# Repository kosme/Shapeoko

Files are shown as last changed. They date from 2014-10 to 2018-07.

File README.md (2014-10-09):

#Folder Structure#

##Upgrades##
Contains the folders of each of the upgrades

###xAxisPlate###
Upgrade for obtaining another 40mm of effective cutting length on the X axis by replacing the motor mount and the Z axis face plate.

##README.md##
This document in markdown format.

<br />This work is licensed under a <a rel="license" href="http://creativecommons.org/licenses/by-nc-sa/4.0/">Creative Commons Attribution-NonCommercial-ShareAlike 4.0 International License</a>.

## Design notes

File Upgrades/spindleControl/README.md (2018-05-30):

This shield implements several hacks for my Shapeoko CNC.

1. It disconnects the A-axis stepper motor signals. Now the source for that stepper are the Y-axis control signals. This enables to use a 2 motor Y-axis configuration.
2. It connects pin 11 of the Arduino to an optocoupler to control the spindle speed and activity.
3. It exposes pin 9, 10, and 12 so that they can be easily used to connect limit switches.
4. It exposes all the analog pins for custom implementations.
5. It provides a 5V and Gnd power rails to facilitate powering external accesories.

**Atention**

1. The pinout it uses is based on the original Arduino Stepper Shield. This pinout was later changed so this may not work with your shield.
2. It relies on a hack that connects the PWM signal for the spindle also to pin 12 on the Stepper Shield. This is not an elegant solution but does the trick since that pin is not connected to anything on the Stepper Shield.

All the files can be opened on Kicad 4+.

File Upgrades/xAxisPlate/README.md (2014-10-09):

Attention:

On the file Part1.dxf, the red lines should be verified. There are TWO screw sizes for the delrin Z-axis nut (5mm or 6mm) so the red figures should be adjusted to match the screw size on your machine.

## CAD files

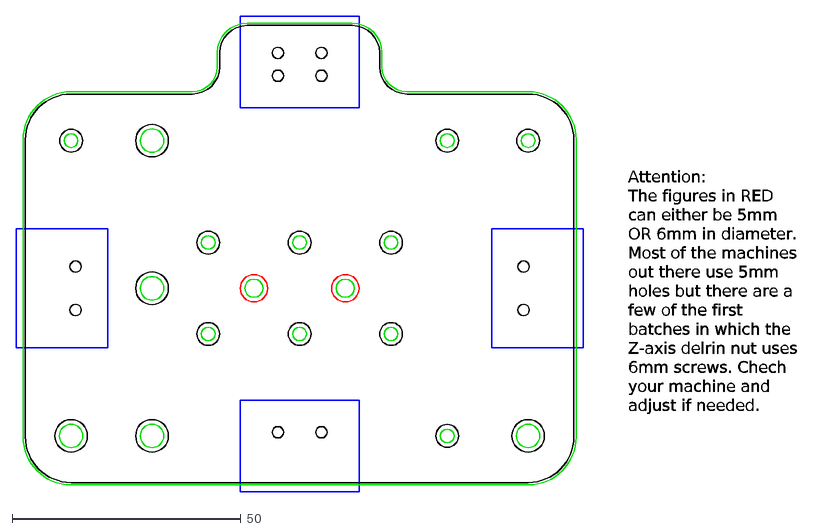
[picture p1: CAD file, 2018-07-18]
Upgrades/xAxisPlate/Part1.dxf
Attention: The figures in RED can either be 5mm OR 6mm in diameter. Most of the machines out there use 5mm holes but there are a few of the first batches in whi

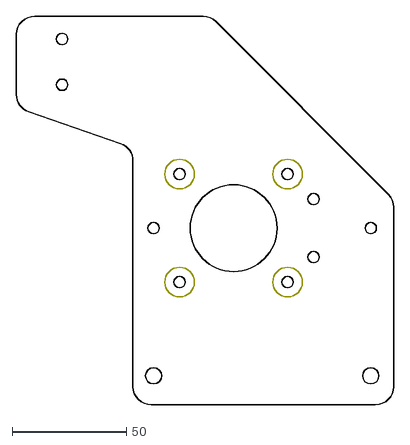
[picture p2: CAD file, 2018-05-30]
Upgrades/yAxisPlate/SM-S01rev3.dxf
165.0 x 170.0

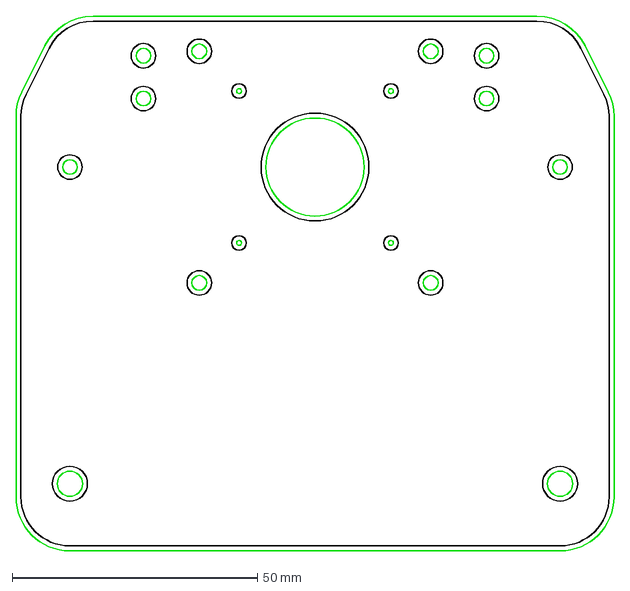
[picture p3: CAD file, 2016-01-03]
Upgrades/xAxisPlate/Part2.dxf
122.0 x 109.1 mm

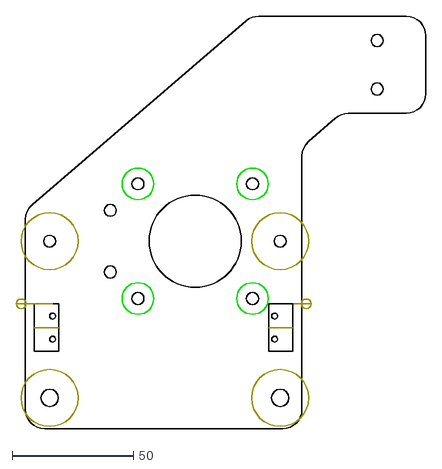
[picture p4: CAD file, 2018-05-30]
Upgrades/yAxisPlate/SM-S01rev2b.dxf
168.8 x 170.0

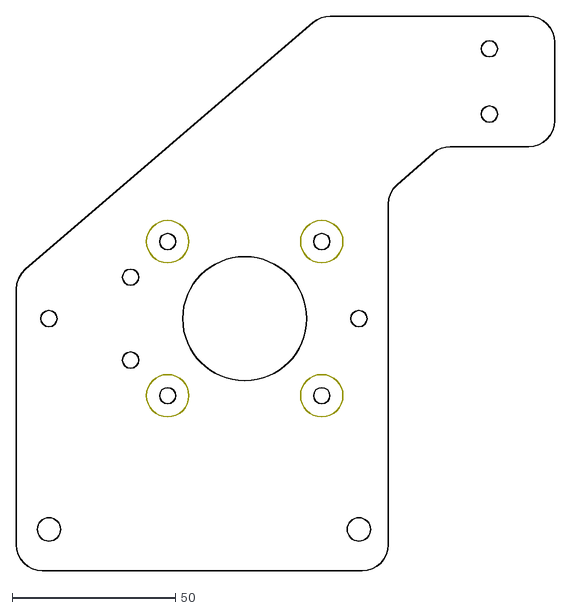
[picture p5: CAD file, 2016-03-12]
Upgrades/yAxisPlate/SM-S01rev2.dxf
165.0 x 170.0

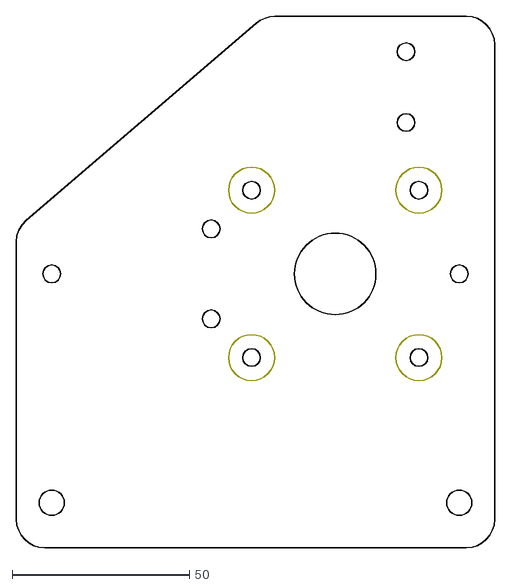
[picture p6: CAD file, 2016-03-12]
Upgrades/yAxisPlate/SM-S01rev1a.dxf
135.0 x 150.0

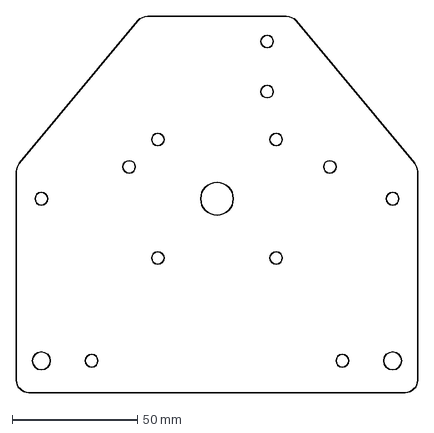
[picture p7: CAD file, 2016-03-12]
Upgrades/yAxisPlate/SM-S01_original.dxf
160.0 x 150.0 mm

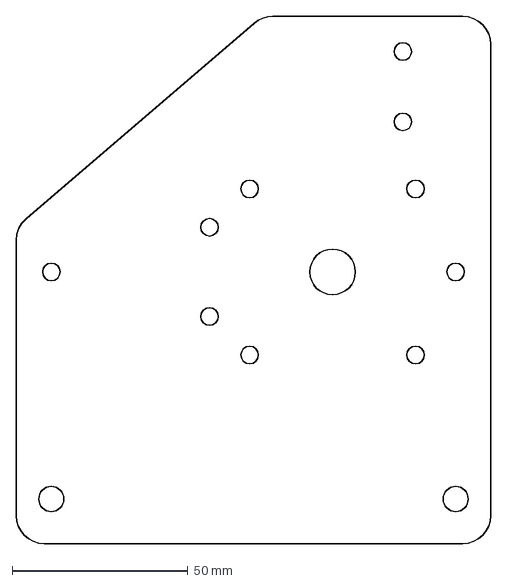
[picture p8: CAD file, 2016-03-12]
Upgrades/yAxisPlate/SM-S01.dxf
135.0 x 150.0 mm

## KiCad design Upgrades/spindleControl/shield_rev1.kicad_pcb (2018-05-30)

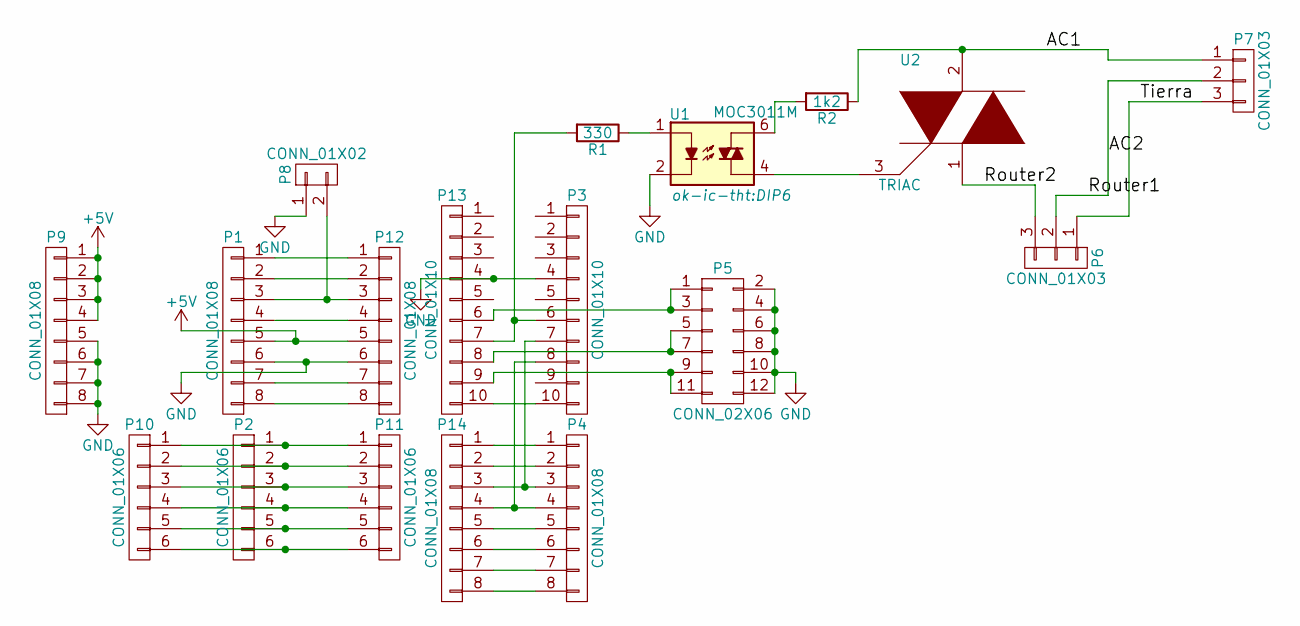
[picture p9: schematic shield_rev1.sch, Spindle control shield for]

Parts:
P1, P4, P9: CONN_01X08; Socket_Strip_Straight_1x08
P2, P10: CONN_01X06; Socket_Strip_Straight_1x06
P3: CONN_01X10; Socket_Strip_Straight_1x10
P5: CONN_02X06; Socket_Strip_Straight_2x06
P6, P7: CONN_01X03; AK300-3
P8: CONN_01X02; AK300-2
P11: CONN_01X06; Pin_Header_Straight_1x06
P12, P14: CONN_01X08; Pin_Header_Straight_1x08
P13: CONN_01X10; Pin_Header_Straight_1x10
R1: 330; Resistor_Horizontal_RM10mm
R2: 1k2; Resistor_Horizontal_RM10mm
U1: MOC3011M; DIP6
U2: TRIAC; TO-220_Neutral123_Horizontal_Reverse_LargePads

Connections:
+5V: P1.5, P9.1, P9.2, P9.3, P9.4, P12.5
/AC1: P7.1, R2.1, U2.2
/AC2: P6.2, P7.2
/Router2: P6.3, U2.1
/Tierra: P6.1, P7.3
GND: P1.6, P3.4, P5.2, P5.4, P5.6, P5.8, P5.10, P5.12, P8.1, P9.5, P9.6, P9.7, P9.8, P12.6, P13.4, U1.2
unnamed: P1.1, P12.1
unnamed: P1.2, P12.2
unnamed: P1.3, P8.2, P12.3
unnamed: P1.4, P12.4
unnamed: P1.7, P12.7
unnamed: P1.8, P12.8
unnamed: P2.1, P10.1, P11.1
unnamed: P2.2, P10.2, P11.2
unnamed: P2.3, P10.3, P11.3
unnamed: P2.4, P10.4, P11.4
unnamed: P2.5, P10.5, P11.5
unnamed: P2.6, P10.6, P11.6
unnamed: P5.1, P5.3, P13.6
unnamed: P3.6, P13.7, R1.2
unnamed: P5.5, P5.7, P13.8
unnamed: P5.9, P5.11, P13.9
unnamed: P3.10, P13.10
unnamed: P4.1, P14.1
unnamed: P4.2, P14.2
unnamed: P3.7, P4.3, P14.3
unnamed: P3.8, P4.4, P14.4
unnamed: P4.5, P14.5
unnamed: P4.6, P14.6
unnamed: P4.7, P14.7
unnamed: P4.8, P14.8
unnamed: R1.1, U1.1
unnamed: R2.2, U1.6
unnamed: U1.4, U2.3

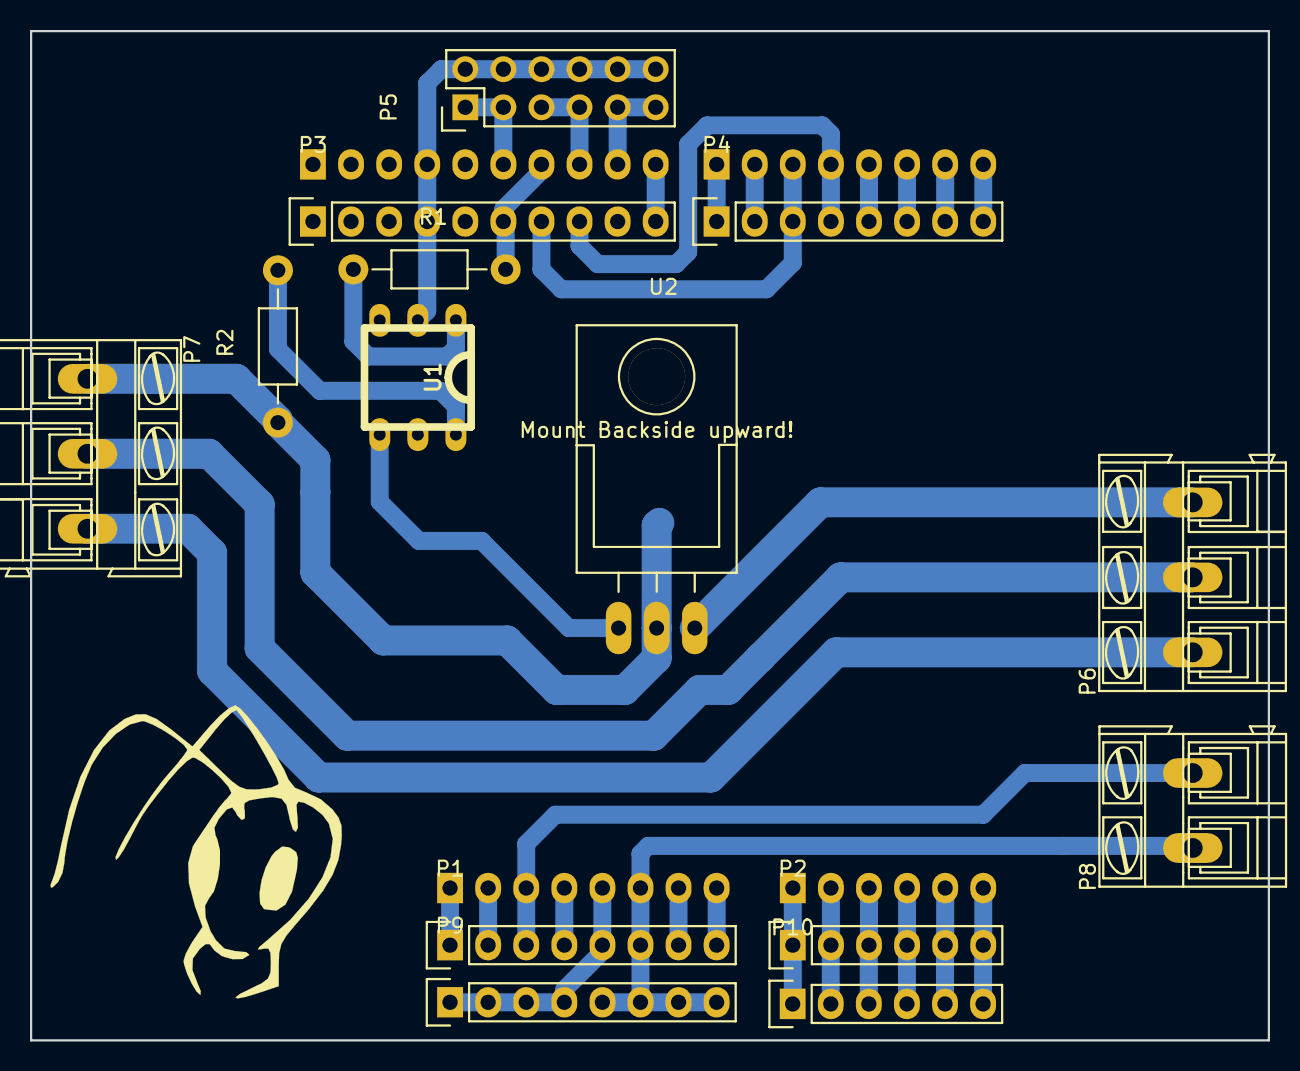
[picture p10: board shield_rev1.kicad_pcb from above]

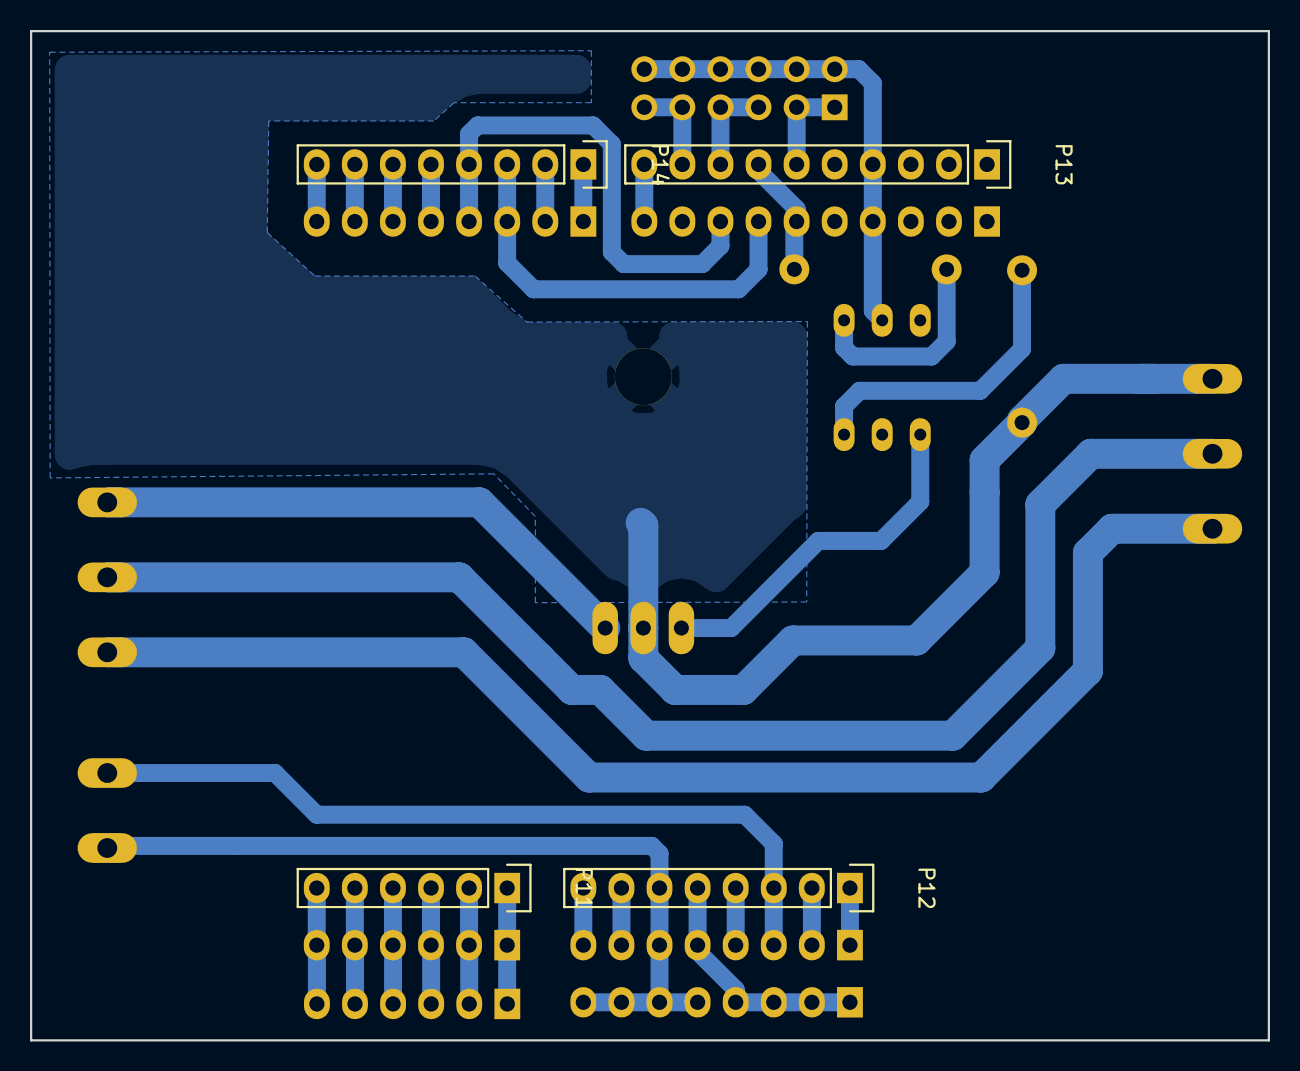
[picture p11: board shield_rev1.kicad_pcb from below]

Board: 2 copper layers, 82.5 x 67.3 mm, 18 parts (4 on the bottom side), 34 nets.

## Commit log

2014-10-09 - X-axis length upgrade.
    [Part1.dxf, Part2.dxf]
2016-01-03 - Added aditional holes for pulley installation. - Changed motor mounting hole diameter to acomodate its protruding circle.
    [Part2.dxf]
2016-03-12 Original plate and first revision
    Shorten the plate by 25 mm and remove one idler mounting hole
    [SM-S01_original.dxf, SM-S01rev1.dxf]
2016-03-12 Increase motor center hole diamater
    [SM-S01rev1a.dxf]
2016-03-12 Reduce length and displace mouting holes
    - Reduce the plate length by 21 mm.
    - Move back the X axis mounting holes 35 mm to avoid the tool from
    hitting the front plate.
    - Move the X axis mounting holes 20 mm up to increase the movement range
    in Z
    - Increase the diameter of the central motor mounting hole so it can
    allocate the protruding part of the motor.
    [SM-S01rev2.dxf]
2018-05-30 Development history
    [SM-S01.dxf, SM-S01rev2b.dxf, SM-S01rev3.dxf]
2018-05-30 Spindle control shield
    [shield_rev1.kicad_pcb, shield_rev1.sch]
2018-05-30 Fix offset layer and add holes for end stops
    [Part1.dxf]
2018-05-31 Relocate shield files
    [shield_rev1.kicad_pcb, shield_rev1.sch]
2018-05-31 Comments on schematic
    [shield_rev1.sch]
2018-07-18 Supports for endstops
    [Part1.dxf]
